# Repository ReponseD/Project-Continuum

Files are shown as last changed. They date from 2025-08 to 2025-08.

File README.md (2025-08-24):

# Project Continuum

### Building Africa’s Independent Robotics & Engineering Ecosystem for the 22nd Century

---

## Introduction
Project Continuum is an **African-led initiative** to create a self-sustaining robotics and technology ecosystem. Our goal is to empower students to innovate, build, and compete **without reliance on expensive imported kits or foreign programs**.  

Project Continuum is not just a robotics program—it is a **movement** preparing Africa for the next century of innovation.

---

## The Story Behind Project Continuum
We began as a **FIRST LEGO League (FLL) team** supported by the Rwanda Basic Education Board. For many students, it was the first time ever seeing and interacting with a LEGO robot, unlocking imagination, problem-solving, and teamwork.  

After graduation, we faced barriers:
- **FTC kits cost over $5,000 USD** (excluding shipping).  
- Most families lived on **less than $1/day**.  
- Attempts to ship donated kits from the U.S. resulted in only 4 out of 21 kits arriving.  
- **FRC competitions** were completely out of reach financially and logistically.  

Despite starting an international African FRC team and qualifying for competitions, we could not raise sufficient funds to travel and compete.  

These challenges gave birth to **Project Continuum**: an ecosystem that Africa controls, builds, and sustains independently.

---

## Why Project Continuum Matters
1. **Accessibility** – No student should be excluded from robotics and engineering due to cost.  
2. **Independence** – Africa must create its own technology platforms and ecosystems.  
3. **Continuity** – A complete pipeline from beginner robotics to advanced AI and engineering.  
4. **Future-Readiness** – Equipping Africa’s youth to lead global innovation by 2100.  

---

## Our Mission
Project Continuum builds an **independent African ecosystem for robotics and advanced technology**, combining:
- **Affordable, locally manufacturable kits** for schools and students.  
- **Curriculum and training programs** to teach problem-solving, critical thinking, and technical skills.  
- **Competitions and challenges** that are accessible, inclusive, and scalable.  
- **Startup incubation pathways** linking student innovation to commercial ventures.  

---

## How We Work
- **Design & Manufacturing** – Open-source hardware and software kits produced locally.  
- **Education & Training** – Step-by-step programs, mentorship, and hands-on learning.  
- **Competitions & Challenges** – Structured to inspire creativity, innovation, and teamwork.  
- **Incubation & Entrepreneurship** – Students transition from learning to launching startups.  
- **Community Collaboration** – Engineers, educators, students, and partners co-develop the ecosystem.  

---

## Vision for 2100
By the end of this century, Africa will no longer be a consumer of technology—it will be a **global leader in robotics, AI, and engineering innovation**.  

Project Continuum ensures that today’s African students grow into tomorrow’s leaders, entrepreneurs, and innovators, creating a sustainable ecosystem that spans education, industry, and research.

---

## Call to Action
Project Continuum is **open-source and collaborative**. We invite:  
- **Developers & Engineers** – Contribute to kits, software, and robotics platforms.  
- **Educators & Mentors** – Guide and train students across Africa.  
- **Partners & Sponsors** – Support the ecosystem through funding, resources, and mentorship.  
- **Students & Innovators** – Learn, build, and lead the future of technology in Africa.  

📧 Contact: **kaleeba.isma@gmail.com**

---

## License
This project is licensed under the **MIT License**, allowing open collaboration, innovation, and reuse.  

---

> Project Continuum is more than a robotics program; it is Africa’s declaration of independence in technology and innovation.

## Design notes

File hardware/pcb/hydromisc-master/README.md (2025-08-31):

# Hydroponics Core PCB Documentation

## Overview
The Hydroponics Core PCB is the central electronic system responsible for powering, sensing, and controlling the hydroponics unit.  
It ensures stable operation of pumps, sensors, and communication modules, while providing clean and reliable measurements of critical parameters such as **pH, EC (electrical conductivity), temperature, and nutrient delivery**.

This design is based on a tested open-source PCB (rev C) with modifications and integration into our hydroponics system goals.  
Robotics functions are excluded here (they will be used separately for harvesting and cleaning).

---

## Functional Blocks

### 1. **Microcontroller Core (ESP32)**
- The ESP32 acts as the brain of the system.
- Handles sensor acquisition, control logic, and communication (WiFi/Bluetooth).
- Ensures remote monitoring via dashboard or app.

### 2. **Power Regulation (LM2596 Switching Regulator)**
- Converts input supply (typically 12V) into stable 5V and 3.3V rails.
- Supports pumps, sensors, and the ESP32.
- Pulldown resistors prevent floating voltages under light loads.

### 3. **pH & EC Measurement**
- High-impedance input stage ensures accurate readings from pH probes.
- Passive low-pass filters reduce noise caused by long probe wires.
- EC measurement supported via analog signal conditioning.

### 4. **Environmental Sensors**
- Supports temperature sensors and humidity probes.
- Inputs conditioned for stable analog-to-digital conversion.

### 5. **I/O Expansion for Hydroponics**
- Pump and valve driver outputs (to control nutrient dosing and irrigation).
- Sensor headers for pH, EC, water level, and temperature.
- Communication headers for future expansions.

---

## How It Fits Our Hydroponics Project
This PCB is the **core control hub** of our hydroponics system. It ensures:
- **Stable power distribution** to pumps, valves, and sensors.
- **Accurate water quality monitoring** (pH, EC, temperature).
- **Remote monitoring and logging** through ESP32’s wireless connectivity.
- **Modular expansion** for additional dosing pumps or future sensors.

While robots will handle **harvesting and cleaning**, this PCB focuses solely on **system operation and nutrient control**.

---

## Technical Specs
- **Board Type:** 2-layer, 1.6mm FR4, 1 oz copper
- **Microcontroller:** ESP32-WROOM
- **Power Input:** 12V DC
- **Power Rails:** 5V, 3.3V regulated
- **Interfaces:** pH probe (BNC), EC probe, temperature sensors, pump drivers
- **Noise Reduction:** Passive low-pass filter on pH lines
- **Form Factor:** Compact, fits standard hydroponics control enclosures

---

## Conclusion
The Hydroponics Core PCB provides a reliable, noise-optimized, and expandable foundation for running automated hydroponics.  
It integrates sensing, power management, and control into a single board — making it the **heart of our Agriculture 4.0 hydroponics project**.

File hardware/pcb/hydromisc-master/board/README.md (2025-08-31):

There are three revisions of the PCB:

* rev A - I built this, and it works except that I forgot the pull-up on
ESP32_EN. Solder a 10k resistor from ESP32_EN to +3V3 (for example, near
CN15), or else the ESP32 module won't start when the programmer is
disconnected.

* rev B - This adds the missing pull-up, as R54. It also adds R55 and
R56 from Vuser to ground, enabling use of LM2596 parts from vendors
(e.g. ON Semi) that have much higher leakage current than the National/TI
original, up to 2 mA! A lightly-loaded Vuser may lose regulation when
Ileakage\*Rpulldown > Vsetpoint, and that R was previously just the
feedback divider.

* rev C - This adds capacitors to create a passive low-pass on the pH
inputs, improving 60 Hz (or 50 Hz) rejection and thus reducing noise
e.g. when the probe is connected with long wires. It also changes the
series resistors between Vref and the BNC shield from 1k to zero-ohm,
since the shunt regulator that makes Vref can survive a short-circuit
to ground with no problem and that resistance worsens noise performance.

The head revision in git is rev C; but I've never actually built this
revision, so it's possible there's still a mistake. That risk should be
very small, though. I'll amend this note if/when someone builds rev C
and reports back.

This is a two-layer board, designed to PCBWay's standard design rules.
Almost any vendor should be able to make this, though. 1.6mm thick,
1 oz/ft^2 copper.

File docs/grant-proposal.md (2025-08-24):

# Grant Proposal Letter for Project Continuum

**Date**: August 17, 2025  
**To**: [Grant Organization Name, e.g., Google.org Impact Challenge]  
**Address**: [Grant Organization Address or "Via Online Submission"]  
**Subject**: Funding Proposal for Project Continuum – Advancing African STEM Education through Sustainable Robotics  

Dear [Grant Organization Contact or "Grant Review Committee"],  

On behalf of Project Continuum, we respectfully submit this proposal to request funding support for an African-led initiative to establish a self-sustaining robotics ecosystem. Based in [Your City, Country], our mission is to empower African youth with accessible, affordable, and locally relevant STEM education through robotics, fostering innovation, economic opportunity, and technical capacity. We seek [Amount, e.g., $150,000 USD] to initiate pilot manufacturing of modular robotics kits, develop open-source curricula, and launch the CRADLE competition framework, addressing the prohibitive costs of imported robotics materials faced by African students.  

## Project Overview  

Project Continuum is a comprehensive platform designed to transform robotics education in Africa through:  

- **Modular Robotics Kits**: Constructed from locally sourced materials (e.g., aluminum, recycled plastics) and off-the-shelf electronics, reducing costs by 30-50% compared to imported kits used in programs like FIRST.  
- **Open-Source Curricula**: Structured learning pathways (beginner to advanced) covering mechanical design, electronics, programming, and systems thinking, tailored to African educational contexts.  
- **CRADLE Competition Framework**: A locally relevant competition platform with challenges inspired by African priorities (e.g., agriculture, water management), prioritizing repairability, cost-efficiency, and inclusivity.  
- **Local Production Network**: Partnerships with regional manufacturers and makerspaces (e.g., RoboTech Africa) to produce and distribute kits, fostering job creation and economic resilience.  
- **Open Repository**: A publicly accessible library of schematics, firmware, lesson plans, and case studies, licensed openly to promote scalability and community ownership.  

Distinct from existing programs that rely on costly imports and external funding, Project Continuum emphasizes self-reliance, accessibility, and cultural relevance, ensuring sustainable STEM education for African youth.  

## Need Statement  

Participation in global robotics programs, such as FIRST, is hindered in Africa by the high cost of imported kits ($500-$6,000 USD per team) and additional expenses from shipping and tariffs (20-50% markups). These barriers restrict access for millions of talented students, limiting opportunities for STEM skill development and economic advancement. Project Continuum addresses this challenge by producing affordable, repairable robotics kits locally and establishing a competition framework (CRADLE) that minimizes financial and logistical barriers, creating an inclusive, scalable STEM ecosystem.  

## Project Goals and Objectives  

Project Continuum will:  

1. Produce 100 affordable robotics kits to equip 10 teams in [Your Region] by Q2 2026, achieving 30-50% cost savings.  
2. Develop open-source curricula for 500 students and launch five CRADLE competitions by Q3 2026, engaging 50 teams.  
3. Establish a social enterprise by 2027, generating $100,000 USD annually through kit sales and competition fees to sustain team sponsorships.  

## Budget Summary  

We request [Amount, e.g., $150,000 USD] to produce 100 modular robotics kits, develop open-source curricula, host five CRADLE competitions, and establish local production partnerships by Q3 2026. Revenue from kit sales ($100 profit per kit) and competition fees ($50 per team) will sustain the project post-grant, funding ongoing team participation (see attached detailed budget).  

## Anticipated Impact  

- **Short-Term (2026)**: Equip 10 teams with affordable kits, train 500 students, and host 5 CRADLE competitions, reaching 1,000 community members.  
- **Long-Term (2027 and Beyond)**: Scale production to 1,000 kits annually, sponsor 5-10 teams per year, and create 20-50 jobs in local manufacturing, fostering a self-reliant STEM ecosystem that showcases African innovation.  
- **Alignment with [Grant Organization]**: This initiative aligns with [e.g., Google.org’s commitment to equitable innovation or ExxonMobil’s focus on STEM capacity building], advancing inclusive education and economic empowerment in Africa.  

## Sustainability Strategy  

Project Continuum is designed for long-term viability:  

- **Revenue Generation**: Generate $145,000 USD annually by 2027 through kit sales, competition fees, and training workshops.  
- **Strategic Partnerships**: Collaborate with organizations such as RoboTech Africa and Robotics Africa to scale production and distribution.  
- **Community Empowerment**: Open-source designs and competition frameworks enable communities to independently adapt and replicate Continuum’s model.  

## Leadership and Partnerships  

Project Continuum is led by [Your Name/Team Name], with expertise in [e.g., robotics engineering, education, or community development]. We have established partnerships with [e.g., local makerspaces, universities, or Robotics Africa] to ensure technical excellence and community engagement. Our advisory board, comprising [e.g., STEM educators, industry leaders], provides strategic oversight to ensure successful implementation.  

## Conclusion  

Project Continuum represents a transformative opportunity to build an African-led, self-sustaining robotics ecosystem that empowers youth, creates economic opportunities, and showcases regional ingenuity. Your investment of [Amount, e.g., $150,000 USD] will catalyze our pilot phase, enabling the production of affordable kits, the launch of CRADLE competitions, and the foundation for a financially independent model. We welcome the opportunity to discuss how Project Continuum aligns with [Grant Organization]’s mission and invite you to contact us at [Your Email/Phone] or visit our repository at [Your Repository URL, if available].  

Thank you for considering this proposal to advance STEM education and innovation in Africa.  

Sincerely,  
[Your Full Name]  
[Your Title, e.g., Project Director, Continuum]  
[Your Organization/Team Name]  
[Your Contact Information]  

**Attachments**:  
- Detailed Budget  
- Project Timeline  
- Letters of Support from Partners

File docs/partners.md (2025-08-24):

# Project Continuum Partners

## Vision

Project Continuum thrives on collaboration. We partner with schools, STEM centers, NGOs, government agencies, and sponsors to empower African students in robotics, AI, and technology innovation.

---

## 1. Schools & Educational Institutions

We work with secondary schools, colleges, and STEM-focused institutions to provide hands-on robotics kits, training, and mentorship programs.

**Current/Pilot Partners:**
- **School A** – Pilot robotics program with 20 students.
- **School B** – STEM club integration with Project Continuum kits.
- **School C** – Participating in first community hackathon.

**Target Partners:**
- 5–10 additional schools in urban and rural areas for program expansion.
- STEM academies and technical colleges for advanced robotics courses.

---

## 2. STEM Centers & Innovation Hubs

Collaborating with centers that provide resources, mentorship, and space for student projects.

**Examples:**
- **Local FabLabs** – Technical support for robot kit fabrication.
- **MakerSpaces** – Hosting workshops and hackathons.
- **Innovation hubs** – Supporting incubation of student-led projects.

---

## 3. NGOs & Community Organizations

Non-profits supporting youth, education, and technology access.

**Potential Collaborators:**
- Organizations promoting girls in STEM.
- Youth empowerment programs for underprivileged communities.
- NGOs funding education and technology initiatives.

---

## 4. Government & Educational Bodies

Partnerships with education ministries and local authorities to expand program reach and credibility.

**Opportunities:**
- Integration into school STEM curricula.
- Access to regional STEM centers and funding support.
- Collaboration on national robotics competitions.

---

## 5. Sponsors & Corporate Partners

Private sector partners provide funding, resources, and mentorship opportunities.

**Potential Partners:**
- Tech companies (hardware/software providers).
- Local businesses interested in community impact.
- International foundations supporting STEM education in Africa.

---

## Collaboration Approach

- Identify common goals: student empowerment, skill development, and innovation.
- Provide clear value propositions for each partner (training, branding, impact).
- Maintain regular communication, updates, and recognition for contributions.
- Develop joint programs, competitions, and incubation opportunities.

---

## Next Steps

- Expand the partner network regionally and nationally.
- Formalize partnerships with Memorandums of Understanding (MoUs).
- Engage partners in upcoming hackathons, workshops, and pilot programs.

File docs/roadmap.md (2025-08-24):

# Project Continuum Roadmap

## Vision

Empower African students with hands-on experience in robotics, AI, and technology innovation through accessible tools, mentorship, and community.

---

## Phase 1: Foundation (0–3 months)

**Goal:**  
Build core infrastructure, community, and pilot framework.

### Key Actions

#### Hardware
- Finalize low-cost, modular robot kit designs suitable for local fabrication.
- Document designs in CAD and schematic formats.
- Create a preliminary Bill of Materials (BOM) with locally available components.

#### Software
- Launch basic firmware and control software on GitHub.
- Include a simple simulator environment for safe testing.
- Write documentation for installation and usage.

#### Community
- Set up GitHub directories: ideas, events, outreach, media.
- Establish communication channels (WhatsApp, Discord, Telegram) for contributors.
- Recruit initial student volunteers for feedback and testing.

#### Documentation
- Publish `strategic-plan.md`, FAQ, and Code of Conduct.
- Prepare a one-page overview for partner schools and sponsors.

### Outputs
- Functional prototype design and BOM.
- Initial GitHub repository with software, simulator, and docs.
- Small network of early student contributors.

---

## Phase 2: Pilot Programs (3–9 months)

**Goal:**  
Test kits and software with real students, gather feedback, and refine the ecosystem.

### Key Actions

#### Hardware Testing
- Produce 10–20 pilot kits using local resources.
- Test kits in 3–5 partner schools for usability and durability.

#### Software Training
- Run introductory workshops (online or in-person) for teachers and students.
- Train student volunteers to help peers use the kits and simulator.

#### Community Engagement
- Collect feedback through surveys and group discussions.
- Encourage students to submit project ideas via GitHub or community platform.

#### Events
- Organize first small-scale hackathon or robotics challenge.
- Document results and share student stories online.

### Outputs
- Refined robot kit and software based on pilot feedback.
- Initial community engagement metrics (number of active students, projects submitted).
- First student-led projects and challenges completed.

---

## Phase 3: Expansion (9–18 months)

**Goal:**  
Grow reach, partnerships, and structured programs.

### Key Actions

#### Partnerships
- Partner with 5–10 additional schools or STEM centers.
- Engage with local NGOs, government STEM programs, and sponsors for support.

#### Community Growth
- Launch online collaboration hub for students to share projects and resources.
- Recruit mentors (older students, alumni, volunteers).

#### Program Scaling
- Organize regional competitions with prizes to motivate students.
- Increase kit production (50–100 kits) with local partners.

#### Incubation Preparation
- Identify top student projects suitable for incubation.
- Develop playbooks and guidelines for future startups.

### Outputs
- Active network of schools and students.
- Regional competitions completed with measurable participation.
- Pipeline of student-led projects for incubation.

---

## Phase 4: Sustainability & Scale (18–36 months)

**Goal:**  
Establish Project Continuum as a sustainable, recognized African STEM program.

### Key Actions

#### Hardware & Software
- Scale kit production to serve dozens of schools.
- Continuously update firmware and simulator based on feedback.

#### Community & Mentorship
- Build mentorship network connecting students with tech professionals.
- Launch training academies and advanced workshops.

#### Events & Competitions
- Host national or regional showcases for student innovations.
- Introduce advanced challenges integrating AI, robotics, and STEM solutions.

#### Funding & Sustainability
- Secure grants, sponsorships, and donations for long-term operations.
- Support student-led startups through incubation, mentorship, and seed funding.

### Outputs
- Self-sustaining ecosystem of schools, students, and mentors.
- Multiple regional competitions and showcases.
- Recognized pipeline of African STEM innovators and student startups.

---

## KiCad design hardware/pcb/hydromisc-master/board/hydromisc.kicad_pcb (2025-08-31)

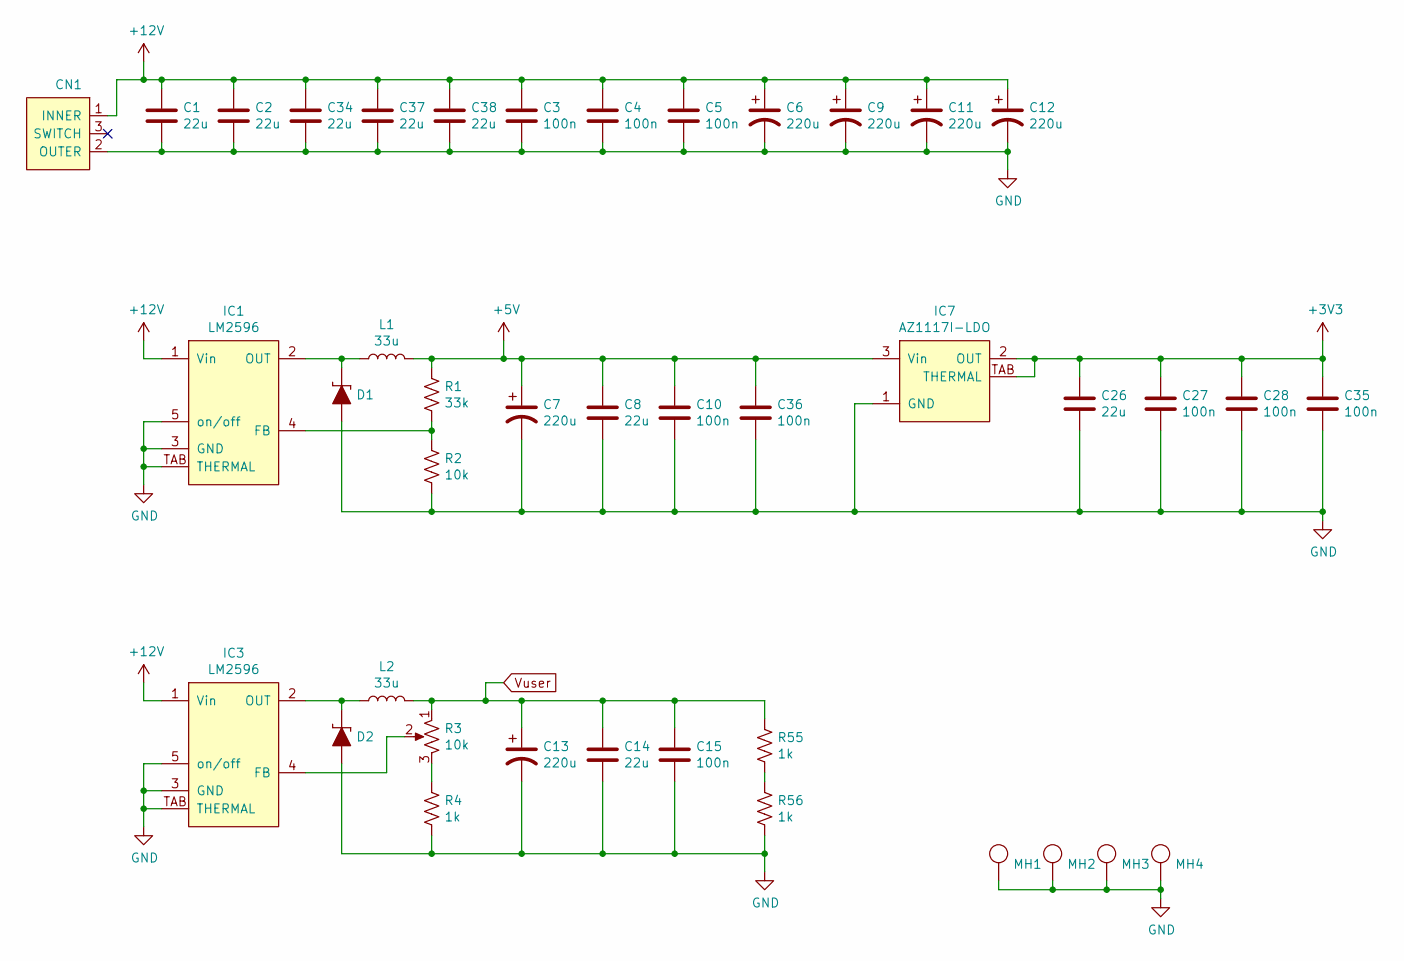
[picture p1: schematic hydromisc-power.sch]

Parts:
C1, C2, C8, C14, C26, C34, C37, C38: 22u; HM_1206
C3, C4, C5, C10, C15, C27, C28, C35, C36: 100n; HM_0603
C6, C7, C9, C11, C12, C13: 220u; HM_C_8MM_3.5MM
CN1: DC_COAX_POWER_NO_SHIELD; HM_DC_COAX_POWER_PJ-102AH
D1, D2: diode-schottky; HM_DIODE_SMB
IC1, IC3: LM2596; HM_TO-263-5
IC7: AZ1117I-LDO; HM_SOT-223
L1, L2: 33u; HM_L_SUMIDA_104CDMCCDS
MH1, MH2, MH3, MH4: MOUNTING_HOLE; HM_MOUNTING_HOLE_6MM_3MM
R1: 33k; HM_0603
R2: 10k; HM_0603
R3: 10k; HM_TRIMPOT_AB_HA06
R4, R55, R56: 1k; HM_0603

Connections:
+3V3: C26.1, C27.1, C28.1, C35.1, IC7.2 (OUT), IC7.TAB (THERMAL); also elsewhere on the board
+5V: C7.1, C8.1, C10.1, C36.1, IC7.3 (Vin), L1.2, R1.1; also elsewhere on the board
+12V: C1.1, C2.1, C3.1, C4.1, C5.1, C6.1, C9.1, C11.1, C12.1, C34.1, C37.1, C38.1, CN1.1 (INNER), IC1.1 (Vin), IC3.1 (Vin); also elsewhere on the board
GND: C1.2, C2.2, C3.2, C4.2, C5.2, C6.2, C7.2, C8.2, C9.2, C10.2, C11.2, C12.2, C13.2, C14.2, C15.2, C26.2, C27.2, C28.2, C34.2, C35.2, C36.2, C37.2, C38.2, CN1.2 (OUTER), D1.A, D2.A, IC1.3 (GND), IC1.5 (on/off), IC1.TAB (THERMAL), IC3.3 (GND), IC3.5 (on/off), IC3.TAB (THERMAL), IC7.1 (GND), MH1.1, MH2.1, MH3.1, MH4.1, R2.2, R4.2, R56.2; also elsewhere on the board
unnamed: D1.K, IC1.2 (OUT), L1.1
unnamed: D2.K, IC3.2 (OUT), L2.1
unnamed: IC1.4 (FB), R1.2, R2.1
unnamed: IC3.4 (FB), R3.2
unnamed: R3.3, R4.1
unnamed: R55.2, R56.1
Vuser: C13.1, C14.1, C15.1, L2.2, R3.1, R55.1; also elsewhere on the board

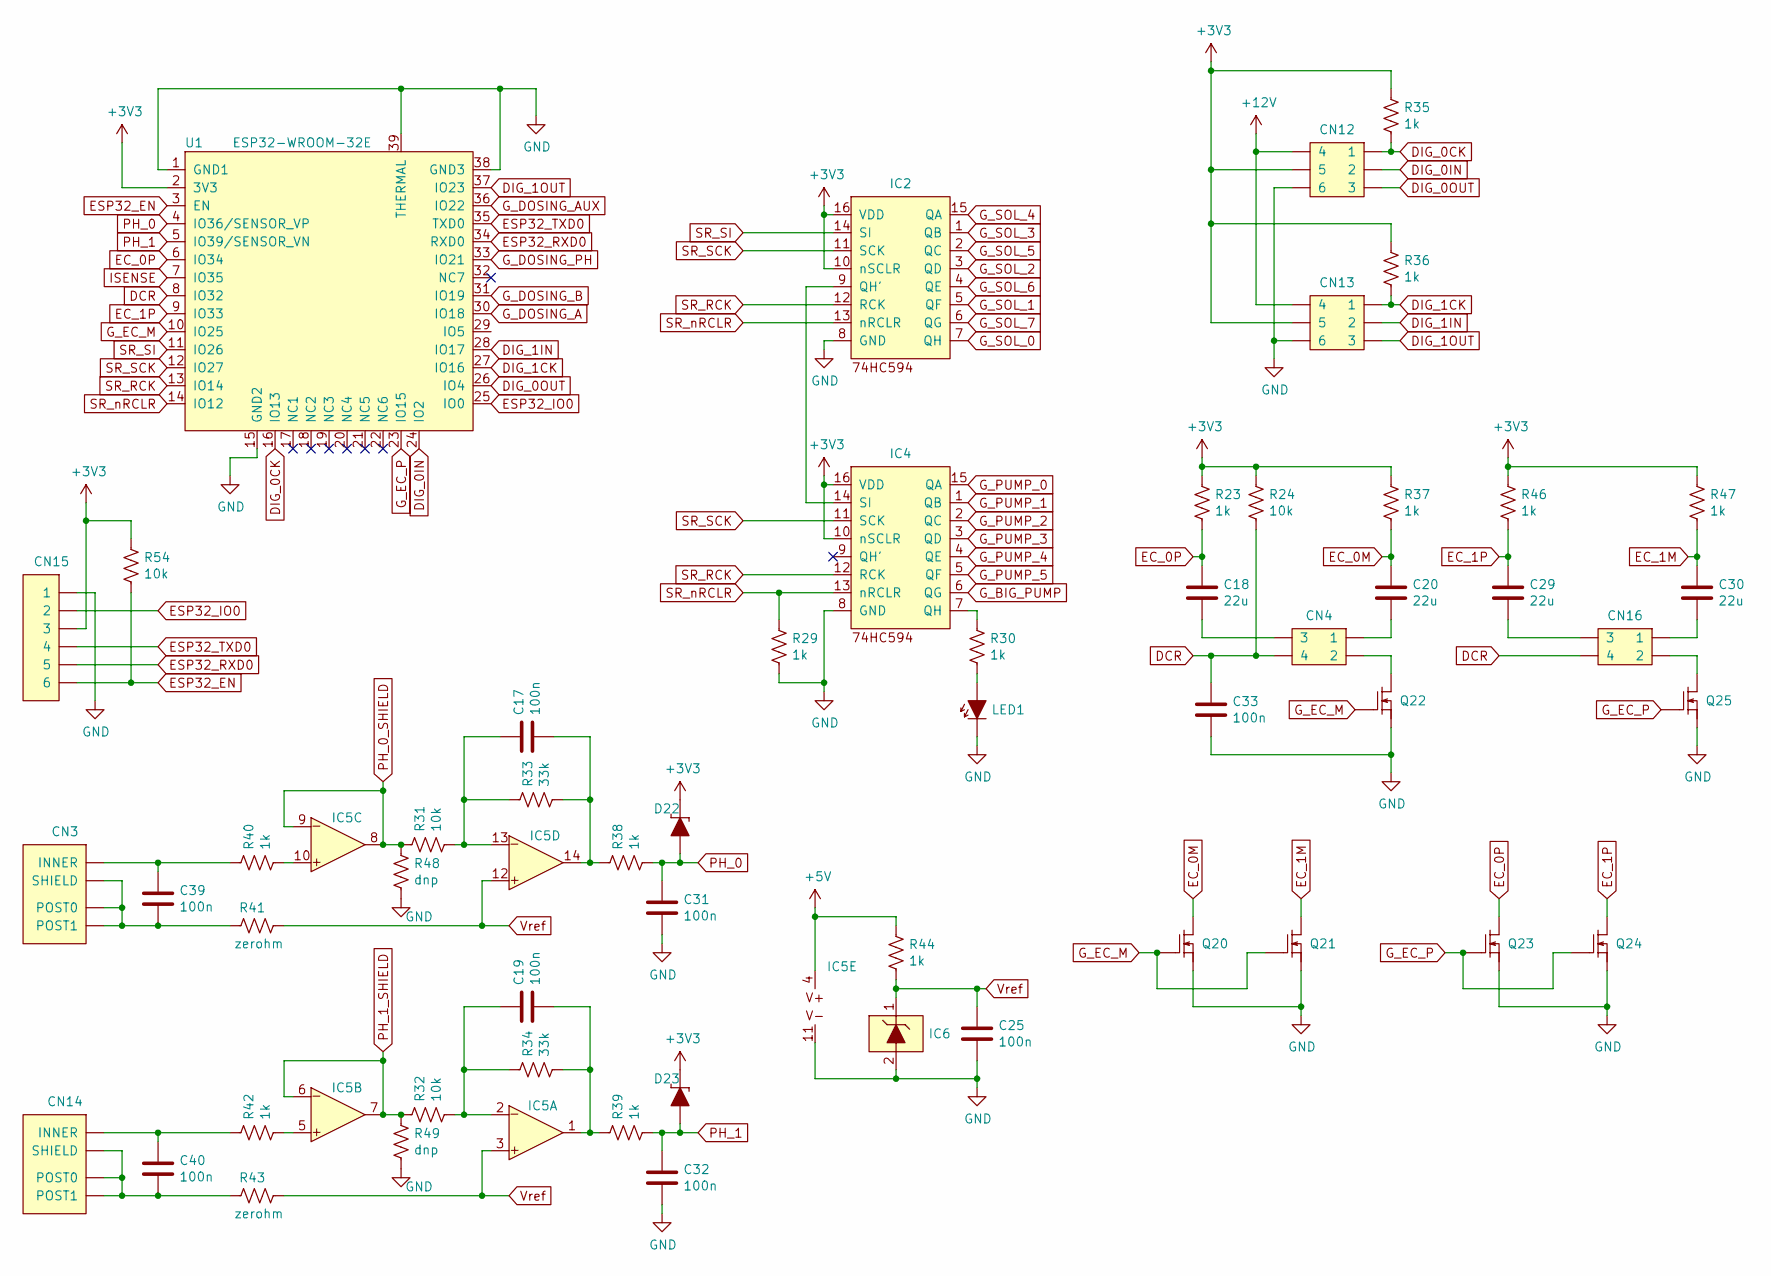
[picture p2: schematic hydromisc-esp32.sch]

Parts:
C17, C19, C25, C31, C32, C33, C39, C40: 100n; HM_0603
C18, C20, C29, C30: 22u; HM_1206
CN3, CN14: COAX_CONNECTOR; HM_BNC_MOLEX_TH_RA
CN4, CN16: MOLEX_2x2; HM_MOLEX_172448_2x2
CN12, CN13: MOLEX_2x3; HM_MOLEX_172448_2x3
CN15: HEADER_6; HM_HEADER_6_0.100_INCH
D22, D23: diode-schottky; HM_SOD-123
IC2, IC4: 74HC594; HM_SOIC-16
IC5: opamp; HM_SOIC-14
IC6: vref-diode; HM_SOT-23_123
LED1: diode-led; HM_LED_CUBE_3MM
Q20, Q21, Q22, Q23, Q24, Q25: NFET; HM_SOT-23_123
R23, R29, R30, R35, R36, R37, R38, R39, R40, R42, R44, R46, R47: 1k; HM_0603
R24, R31, R32, R54: 10k; HM_0603
R33, R34: 33k; HM_0603
R41, R43: zerohm; HM_0603
R48, R49: dnp; HM_0603
U1: ESP32-WROOM-32E; HM_ESP32-WROOM-32E

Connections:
+3V3: CN12.5, CN13.5, CN15.3, D22.K, D23.K, IC2.10 (nSCLR), IC2.16 (VDD), IC4.10 (nSCLR), IC4.16 (VDD), R23.1, R24.1, R35.2, R36.2, R37.1, R46.1, R47.1, R54.1, U1.2 (3V3); also elsewhere on the board
+5V: IC5.4 (V+), R44.1; also elsewhere on the board
+12V: CN12.4, CN13.4; also elsewhere on the board
DCR: C33.1, CN4.4, CN16.4, R24.2, U1.8 (IO32)
DIG_0CK: CN12.1, R35.1, U1.16 (IO13)
DIG_0IN: CN12.2, U1.24 (IO2)
DIG_0OUT: CN12.3, U1.26 (IO4)
DIG_1CK: CN13.1, R36.1, U1.27 (IO16)
DIG_1IN: CN13.2, U1.28 (IO17)
DIG_1OUT: CN13.3, U1.37 (IO23)
EC_0M: C20.1, Q20.3 (D), R37.2
EC_0P: C18.1, Q23.3 (D), R23.2, U1.6 (IO34)
EC_1M: C30.1, Q21.3 (D), R47.2
EC_1P: C29.1, Q24.3 (D), R46.2, U1.9 (IO33)
ESP32_EN: CN15.6, R54.2, U1.3 (EN)
ESP32_IO0: CN15.2, U1.25 (IO0)
ESP32_RXD0: CN15.5, U1.34 (RXD0)
ESP32_TXD0: CN15.4, U1.35 (TXD0)
GND: C25.2, C31.2, C32.2, C33.2, CN12.6, CN13.6, CN15.1, IC2.8 (GND), IC4.8 (GND), IC5.11 (V-), IC6.2 (-), LED1.K, Q20.2 (S), Q21.2 (S), Q22.2 (S), Q23.2 (S), Q24.2 (S), Q25.2 (S), R29.2, R48.2, R49.2, U1.1 (GND1), U1.15 (GND2), U1.38 (GND3), U1.39 (THERMAL); also elsewhere on the board
G_BIG_PUMP: IC4.6 (QG); also elsewhere on the board
G_DOSING_A: U1.30 (IO18); also elsewhere on the board
G_DOSING_AUX: U1.36 (IO22); also elsewhere on the board
G_DOSING_B: U1.31 (IO19); also elsewhere on the board
G_DOSING_PH: U1.33 (IO21); also elsewhere on the board
G_EC_M: Q20.1 (G), Q21.1 (G), Q22.1 (G), U1.10 (IO25)
G_EC_P: Q23.1 (G), Q24.1 (G), Q25.1 (G), U1.23 (IO15)
G_PUMP_0: IC4.15 (QA); also elsewhere on the board
G_PUMP_1: IC4.1 (QB); also elsewhere on the board
G_PUMP_2: IC4.2 (QC); also elsewhere on the board
G_PUMP_3: IC4.3 (QD); also elsewhere on the board
G_PUMP_4: IC4.4 (QE); also elsewhere on the board
G_PUMP_5: IC4.5 (QF); also elsewhere on the board
G_SOL_0: IC2.7 (QH); also elsewhere on the board
G_SOL_1: IC2.5 (QF); also elsewhere on the board
G_SOL_2: IC2.3 (QD); also elsewhere on the board
G_SOL_3: IC2.1 (QB); also elsewhere on the board
G_SOL_4: IC2.15 (QA); also elsewhere on the board
G_SOL_5: IC2.2 (QC); also elsewhere on the board
G_SOL_6: IC2.4 (QE); also elsewhere on the board
G_SOL_7: IC2.6 (QG); also elsewhere on the board
ISENSE: U1.7 (IO35); also elsewhere on the board
unnamed: C17.1, IC5.13 (D-), R31.2, R33.1
unnamed: C17.2, IC5.14 (DOUT), R33.2, R38.1
unnamed: C18.2, CN4.3
unnamed: C19.1, IC5.2 (A-), R32.2, R34.1
unnamed: C19.2, IC5.1 (AOUT), R34.2, R39.1
unnamed: C20.2, CN4.1
unnamed: C29.2, CN16.3
unnamed: C30.2, CN16.1
unnamed: C39.1, CN3.INNER, R40.1
unnamed: C39.2, CN3.POST0, CN3.POST1, CN3.SHIELD, R41.1
unnamed: C40.1, CN14.INNER, R42.1
unnamed: C40.2, CN14.POST0, CN14.POST1, CN14.SHIELD, R43.1
unnamed: CN4.2, Q22.3 (D)
unnamed: CN16.2, Q25.3 (D)
unnamed: IC2.9 (QH'), IC4.14 (SI)
unnamed: IC4.7 (QH), R30.1
unnamed: IC5.5 (B+), R42.2
unnamed: IC5.10 (C+), R40.2
unnamed: LED1.A, R30.2
PH_0: C31.1, D22.A, R38.2, U1.4 (IO36/SENSOR_VP)
PH_0_SHIELD: IC5.8 (COUT), IC5.9 (C-), R31.1, R48.1
PH_1: C32.1, D23.A, R39.2, U1.5 (IO39/SENSOR_VN)
PH_1_SHIELD: IC5.6 (B-), IC5.7 (BOUT), R32.1, R49.1
SR_RCK: IC2.12 (RCK), IC4.12 (RCK), U1.13 (IO14)
SR_SCK: IC2.11 (SCK), IC4.11 (SCK), U1.12 (IO27)
SR_SI: IC2.14 (SI), U1.11 (IO26)
SR_nRCLR: IC2.13 (nRCLR), IC4.13 (nRCLR), R29.1, U1.14 (IO12)
Vref: C25.1, IC5.3 (A+), IC5.12 (D+), IC6.1 (+), R41.2, R43.2, R44.2

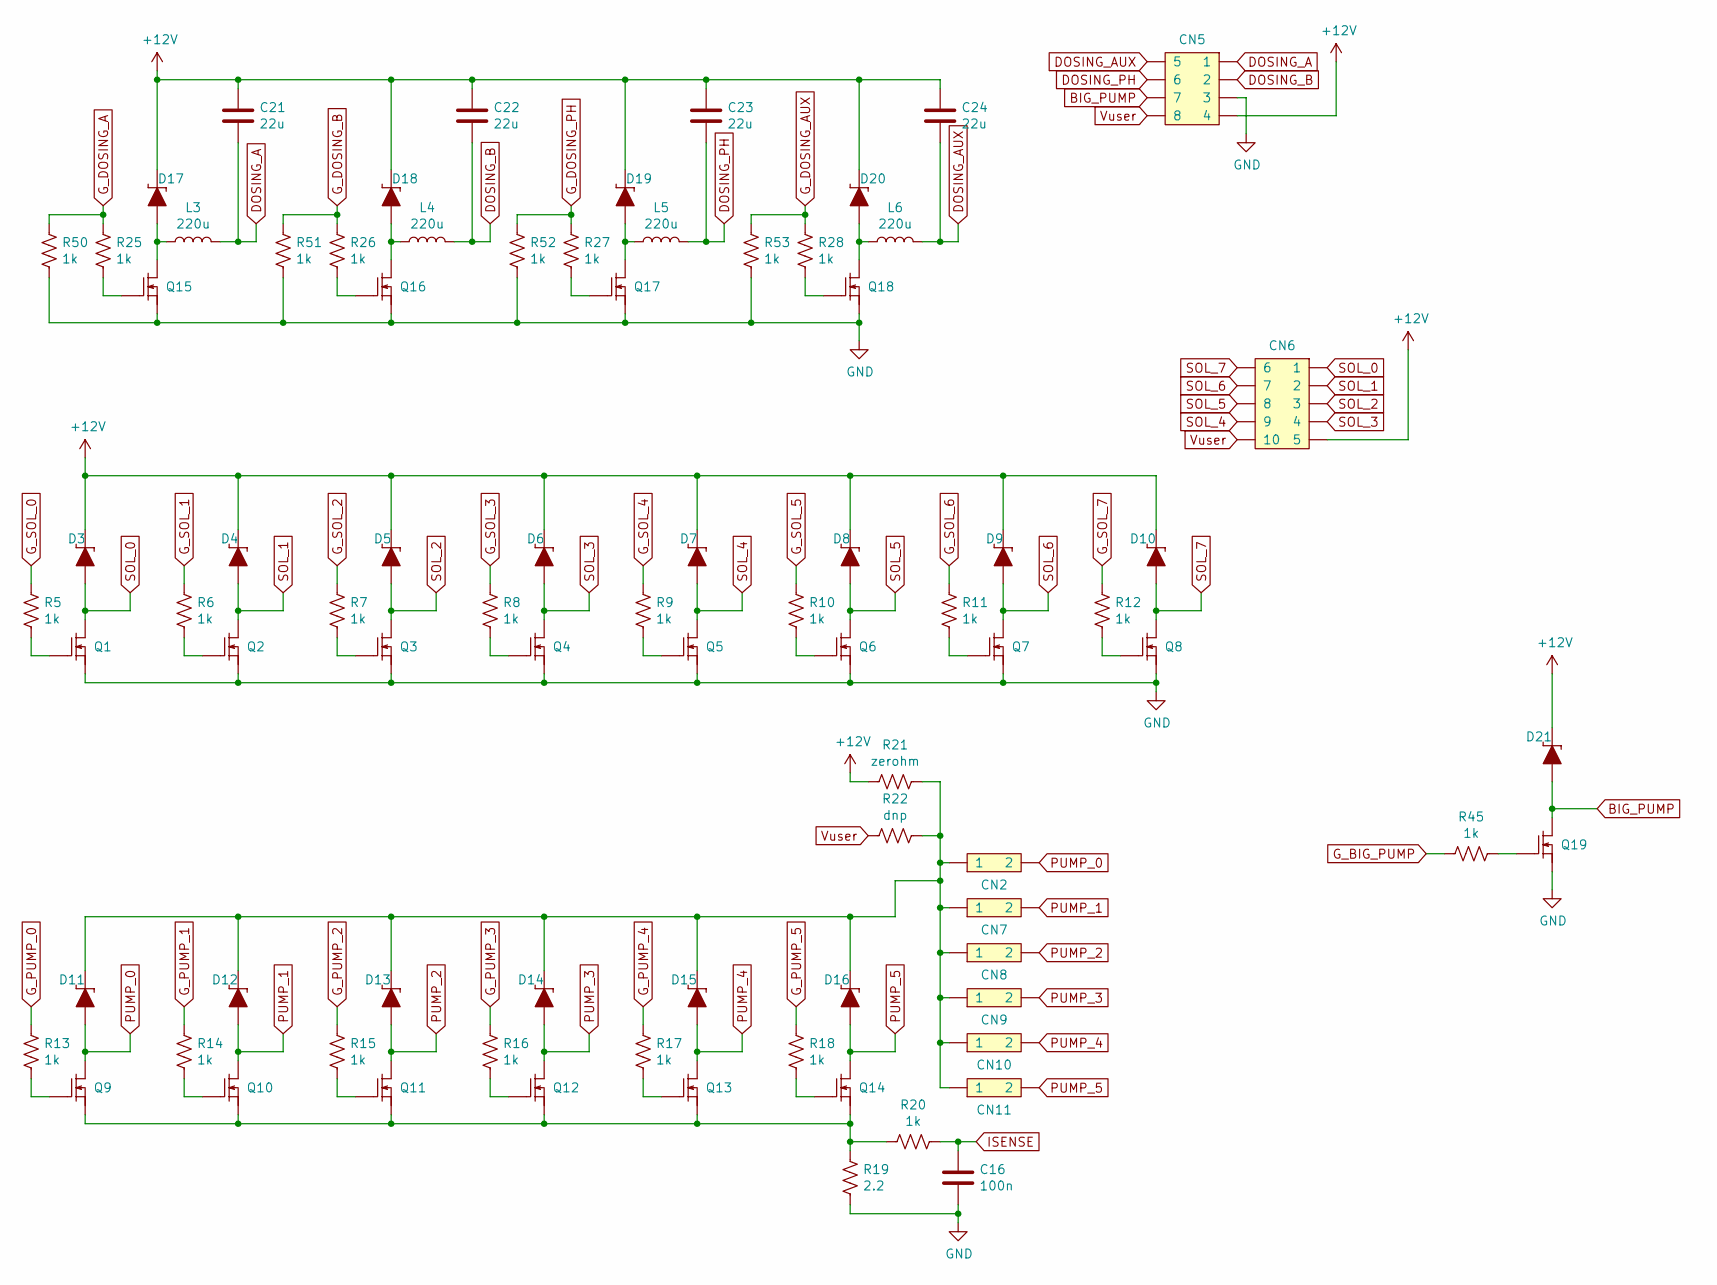
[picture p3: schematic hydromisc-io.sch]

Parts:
C16: 100n; HM_0603
C21, C22, C23, C24: 22u; HM_1206
CN2, CN7, CN8, CN9, CN10, CN11: MOLEX_2x1; HM_MOLEX_172448_2x1
CN5: MOLEX_2x4; HM_MOLEX_172448_2x4
CN6: MOLEX_2x5; HM_MOLEX_172448_2x5
D3, D4, D5, D6, D7, D8, D9, D10, D11, D12, D13, D14, D15, D16, D17, D18, D19, D20, D21: diode-schottky; HM_SOD-123
L3, L4, L5, L6: 220u; HM_L_MURATA_LQH44
Q1, Q2, Q3, Q4, Q5, Q6, Q7, Q8, Q9, Q10, Q11, Q12, Q13, Q14, Q15, Q16, Q17, Q18, Q19: NFET; HM_SOT-23_123
R5, R6, R7, R8, R9, R10, R11, R12, R13, R14, R15, R16, R17, R18, R20, R25, R26, R27, R28, R45, R50, R51, R52, R53: 1k; HM_0603
R19: 2.2; HM_2010
R21: zerohm; HM_1206
R22: dnp; HM_1206

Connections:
+12V: C21.1, C22.1, C23.1, C24.1, CN5.4, CN6.5, D3.K, D4.K, D5.K, D6.K, D7.K, D8.K, D9.K, D10.K, D17.K, D18.K, D19.K, D20.K, D21.K, R21.2; also elsewhere on the board
BIG_PUMP: CN5.7, D21.A, Q19.3 (D)
DOSING_A: C21.2, CN5.1, L3.2
DOSING_AUX: C24.2, CN5.5, L6.2
DOSING_B: C22.2, CN5.2, L4.2
DOSING_PH: C23.2, CN5.6, L5.2
GND: C16.2, CN5.3, Q1.2 (S), Q2.2 (S), Q3.2 (S), Q4.2 (S), Q5.2 (S), Q6.2 (S), Q7.2 (S), Q8.2 (S), Q15.2 (S), Q16.2 (S), Q17.2 (S), Q18.2 (S), Q19.2 (S), R19.1, R50.2, R51.2, R52.2, R53.2; also elsewhere on the board
G_BIG_PUMP: R45.2; also elsewhere on the board
G_DOSING_A: R25.1, R50.1; also elsewhere on the board
G_DOSING_AUX: R28.1, R53.1; also elsewhere on the board
G_DOSING_B: R26.1, R51.1; also elsewhere on the board
G_DOSING_PH: R27.1, R52.1; also elsewhere on the board
G_PUMP_0: R13.1; also elsewhere on the board
G_PUMP_1: R14.1; also elsewhere on the board
G_PUMP_2: R15.1; also elsewhere on the board
G_PUMP_3: R16.1; also elsewhere on the board
G_PUMP_4: R17.1; also elsewhere on the board
G_PUMP_5: R18.1; also elsewhere on the board
G_SOL_0: R5.1; also elsewhere on the board
G_SOL_1: R6.1; also elsewhere on the board
G_SOL_2: R7.1; also elsewhere on the board
G_SOL_3: R8.1; also elsewhere on the board
G_SOL_4: R9.1; also elsewhere on the board
G_SOL_5: R10.1; also elsewhere on the board
G_SOL_6: R11.1; also elsewhere on the board
G_SOL_7: R12.1; also elsewhere on the board
ISENSE: C16.1, R20.1; also elsewhere on the board
unnamed: CN2.1, CN7.1, CN8.1, CN9.1, CN10.1, CN11.1, D11.K, D12.K, D13.K, D14.K, D15.K, D16.K, R21.1, R22.1
unnamed: D17.A, L3.1, Q15.3 (D)
unnamed: D18.A, L4.1, Q16.3 (D)
unnamed: D19.A, L5.1, Q17.3 (D)
unnamed: D20.A, L6.1, Q18.3 (D)
unnamed: Q1.1 (G), R5.2
unnamed: Q2.1 (G), R6.2
unnamed: Q3.1 (G), R7.2
unnamed: Q4.1 (G), R8.2
unnamed: Q5.1 (G), R9.2
unnamed: Q6.1 (G), R10.2
unnamed: Q7.1 (G), R11.2
unnamed: Q8.1 (G), R12.2
unnamed: Q9.1 (G), R13.2
unnamed: Q10.1 (G), R14.2
unnamed: Q9.2 (S), Q10.2 (S), Q11.2 (S), Q12.2 (S), Q13.2 (S), Q14.2 (S), R19.2, R20.2
unnamed: Q11.1 (G), R15.2
unnamed: Q12.1 (G), R16.2
unnamed: Q13.1 (G), R17.2
unnamed: Q14.1 (G), R18.2
unnamed: Q15.1 (G), R25.2
unnamed: Q16.1 (G), R26.2
unnamed: Q17.1 (G), R27.2
unnamed: Q18.1 (G), R28.2
unnamed: Q19.1 (G), R45.1
PUMP_0: CN2.2, D11.A, Q9.3 (D)
PUMP_1: CN7.2, D12.A, Q10.3 (D)
PUMP_2: CN8.2, D13.A, Q11.3 (D)
PUMP_3: CN9.2, D14.A, Q12.3 (D)
PUMP_4: CN10.2, D15.A, Q13.3 (D)
PUMP_5: CN11.2, D16.A, Q14.3 (D)
SOL_0: CN6.1, D3.A, Q1.3 (D)
SOL_1: CN6.2, D4.A, Q2.3 (D)
SOL_2: CN6.3, D5.A, Q3.3 (D)
SOL_3: CN6.4, D6.A, Q4.3 (D)
SOL_4: CN6.9, D7.A, Q5.3 (D)
SOL_5: CN6.8, D8.A, Q6.3 (D)
SOL_6: CN6.7, D9.A, Q7.3 (D)
SOL_7: CN6.6, D10.A, Q8.3 (D)
Vuser: CN5.8, CN6.10, R22.2; also elsewhere on the board

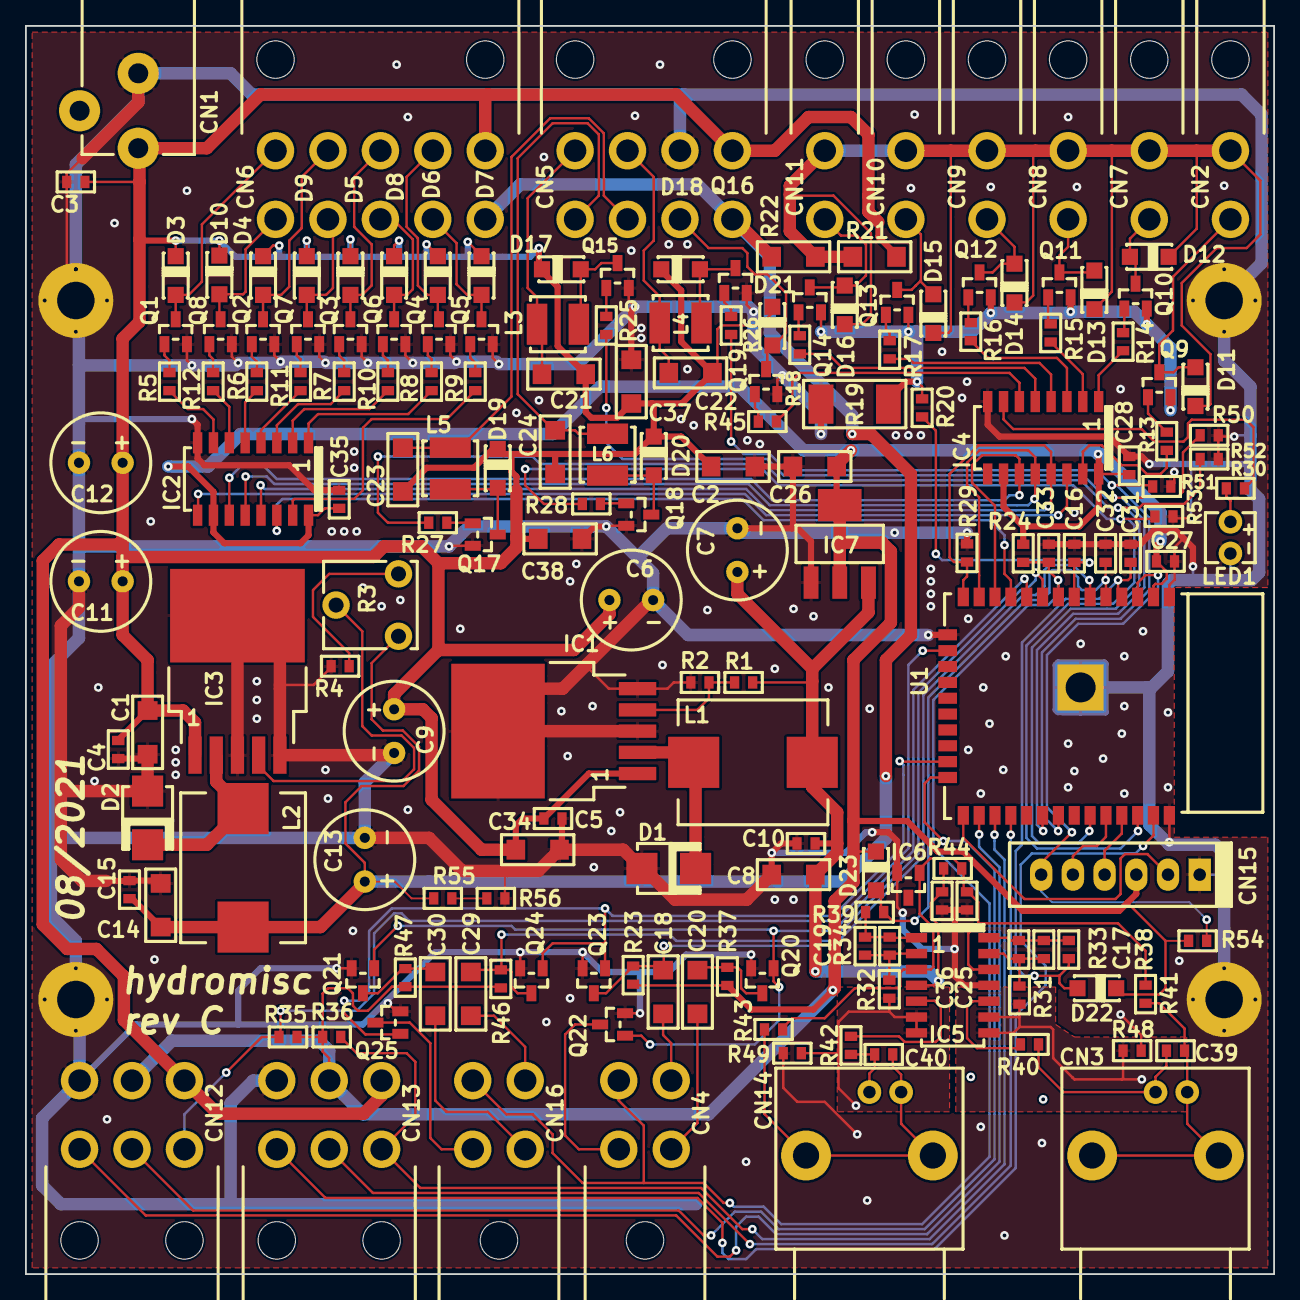
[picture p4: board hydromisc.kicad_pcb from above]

Board: 2 copper layers, 100.0 x 100.0 mm, 179 parts (0 on the bottom side), 120 nets.

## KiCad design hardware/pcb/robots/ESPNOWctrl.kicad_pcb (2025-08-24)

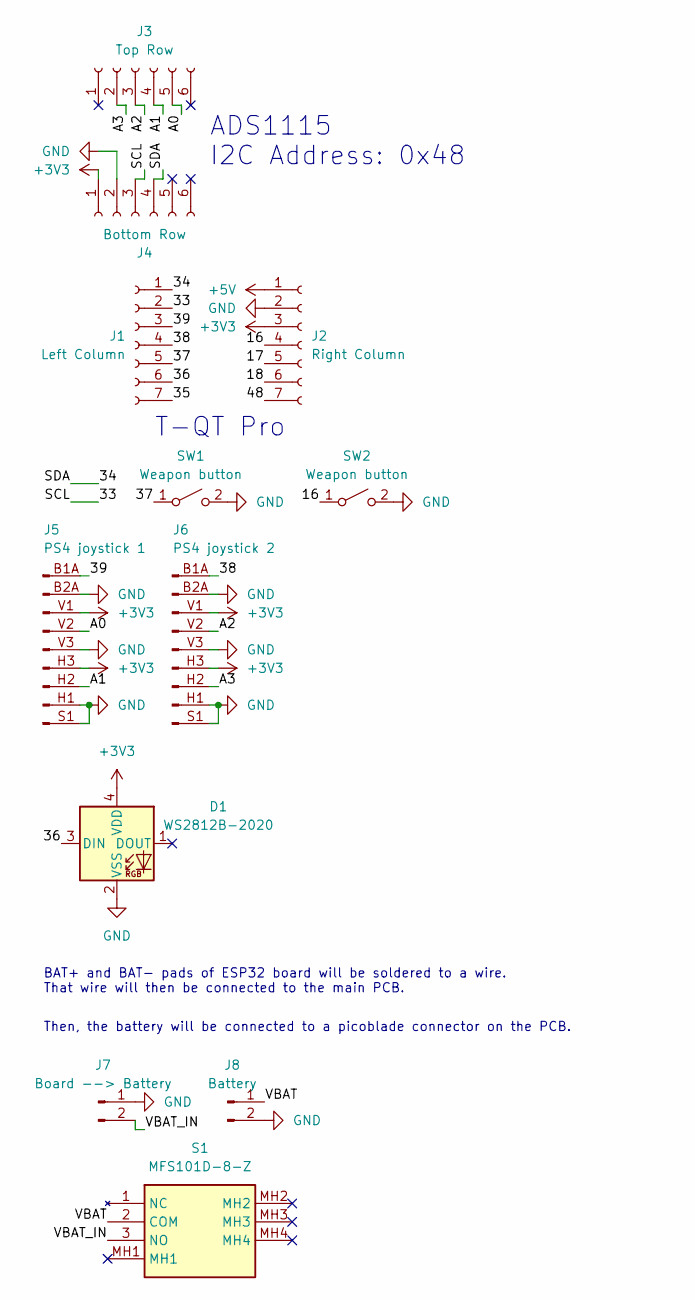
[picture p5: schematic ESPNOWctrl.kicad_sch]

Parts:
D1: WS2812B-2020; LED_WS2812B-2020_PLCC4_2.0x2.0mm
J1: Left Column; PinSocket_1x07_P2.54mm_Vertical
J2: Right Column; PinSocket_1x07_P2.54mm_Vertical
J3: Top Row; PinSocket_1x06_P2.54mm_Vertical
J4: Bottom Row; PinSocket_1x06_P2.54mm_Vertical
J5: PS4 joystick 1; PS4_joystick
J6: PS4 joystick 2; PS4_joystick
J7: Board --> Battery; JST_PH_B2B-PH-K_1x02_P2.00mm_Vertical
J8: Battery; JST_PH_B2B-PH-K_1x02_P2.00mm_Vertical
S1: MFS101D-8-Z; MFS101D8Z; Manufacturer_Part_Number MFS101D-8-Z
SW1, SW2: Weapon button; SW_SPST_Omron_B3F-315x_Angled

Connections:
+3V3: D1.4 (VDD), J2.3, J4.1, J5.H3 (Pin_6), J5.V1 (Pin_3), J6.H3 (Pin_6), J6.V1 (Pin_3)
+5V: J2.1
/16: J2.4, SW2.1 (A)
/17: J2.5
/18: J2.6
/33: J1.2, J4.3
/34: J1.1, J4.4
/35: J1.7
/36: D1.3 (DIN), J1.6
/37: J1.5, SW1.1 (A)
/38: J1.4, J6.B1A (Pin_1), J6.B1B (Pin_1)
/39: J1.3, J5.B1A (Pin_1), J5.B1B (Pin_1)
/48: J2.7
/A0: J3.5, J5.V2 (Pin_4)
/A1: J3.4, J5.H2 (Pin_7)
/A2: J3.3, J6.V2 (Pin_4)
/A3: J3.2, J6.H2 (Pin_7)
/VBAT: J8.1, S1.2 (COM)
/VBAT_IN: J7.2, S1.3 (NO)
GND: D1.2 (VSS), J2.2, J4.2, J5.B2A (Pin_2), J5.B2B (Pin_2), J5.H1 (Pin_8), J5.S1 (Pin_9), J5.S2 (Pin_9), J5.S3 (Pin_9), J5.S4 (Pin_9), J5.V3 (Pin_5), J6.B2A (Pin_2), J6.B2B (Pin_2), J6.H1 (Pin_8), J6.S1 (Pin_9), J6.S2 (Pin_9), J6.S3 (Pin_9), J6.S4 (Pin_9), J6.V3 (Pin_5), J7.1, J8.2, SW1.2 (B), SW2.2 (B)

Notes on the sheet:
T-QT Pro
ADS1115 I2C Address: 0x48
BAT+ and BAT- pads of ESP32 board will be soldered to a wire. That wire will then be connected to the main PCB.
Then, the battery will be connected to a picoblade connector on the PCB.

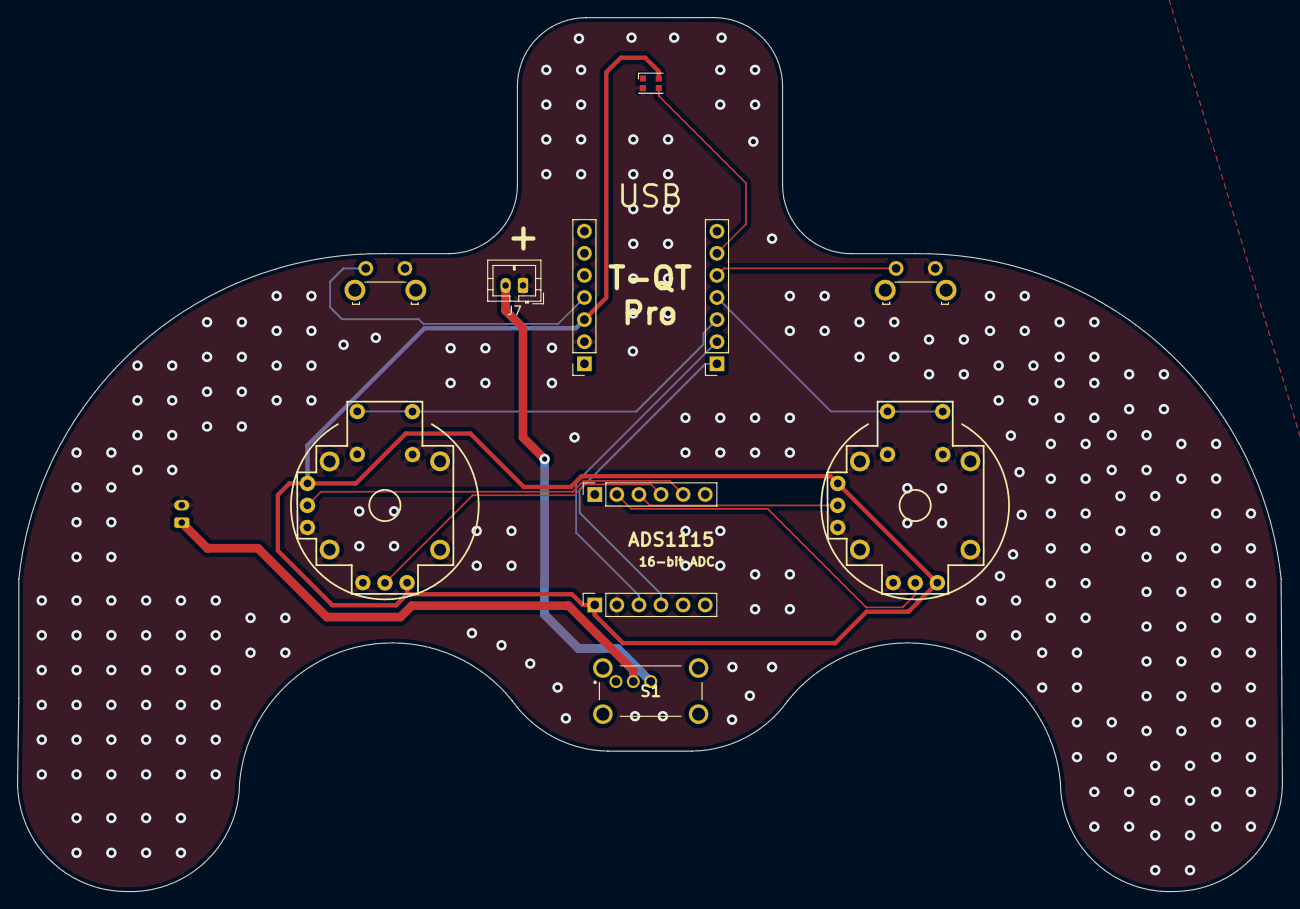
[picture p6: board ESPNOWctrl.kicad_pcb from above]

Board: 2 copper layers, 145.4 x 100.5 mm, 12 parts (1 on the bottom side), 15 nets.

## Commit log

2025-08-24 new pcb designs(in_progress)
    [ESPNOWctrl.kicad_pcb, ESPNOWctrl.kicad_sch, PC brain.kicad_pcb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]
2025-08-31 Hydroponic pcb designs
    [ESPNOWctrl.kicad_pcb, ESPNOWctrl.kicad_sch, PC brain.kicad_pcb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]
